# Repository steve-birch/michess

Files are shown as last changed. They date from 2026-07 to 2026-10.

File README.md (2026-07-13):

# michess ♟️

An open-source NFC-based smart chess board powered by a Raspberry Pi. Place any piece on any square and the board knows exactly what it is and where it is - no setup routine, no special starting position required.

The board uses LEDs embedded behind a wood veneer to indicate the chess engine's moves, creating a clean physical interface for playing against a computer opponent.

---

## Features

- **Full piece identification** - NFC tags in each piece base, detected by a matrix of antennas under the board
- **Arbitrary position recognition** - pick up mid-game, set up a puzzle, analyse a position
- **LED move indicators** - subtle lighting behind the veneer shows the engine's chosen move
- **Stockfish integration** - plays via the standard UCI chess engine interface
- **Open design** - all hardware designs and software are freely available

---

## How It Works

64 NFC antennas sit beneath the board, one per square, managed by a hierarchical multiplexer system. A Raspberry Pi 4 scans the full board in under 2 seconds, determines the game state, passes it to Stockfish, and lights up the appropriate squares.

See [`docs/architecture/`](docs/architecture/) for full system diagrams.

---

## Repository Structure

```
michess/
├── hardware/               # Schematics, PCB layouts, BOM, antenna designs
├── firmware/               # Low-level microcontroller code (if applicable)
├── software/
│   ├── board_reader/       # NFC matrix scanning
│   ├── chess_engine/       # Stockfish/UCI integration
│   └── led_controller/     # LED matrix control
├── development/            # Throwaway hardware/learning test harnesses
├── docs/
│   └── architecture/       # System diagrams and design notes
└── tests/
```

---

## Hardware Requirements

| Component | Quantity | Notes |
|---|---|---|
| Raspberry Pi 4 | 1 | Main controller |
| PN532 NFC reader modules | 8 | One per 8-square group |
| CD74HC4067 16-channel multiplexers | 4 | For antenna switching |
| NFC tags (13.56 MHz) | 32 | Embedded in piece bases |
| Custom loop antennas | 64 | One per square, ~1–2 μH |
| WS2812B LEDs | 64+ | For move indication |

See [`hardware/bom/`](hardware/bom/) for a full bill of materials with UK suppliers and current pricing.

---

## Getting Started

### Software Setup

```bash
# Clone the repo
git clone https://github.com/steve-birch/michess.git
cd michess

# Create a Python virtual environment
python3 -m venv venv
source venv/bin/activate

# Install dependencies
pip install -r requirements.txt

# Run
python software/main.py
```

### Hardware Setup

See [`docs/setup.md`](docs/setup.md) for full wiring instructions and assembly guide.

---

## Licences

This project uses different licences for different parts:

| Part | Licence |
|---|---|
| Software | [GPL-3.0](LICENSE) |
| Hardware designs | [CERN-OHL-S v2](hardware/LICENSE) |
| Documentation | [CC BY-SA 4.0](docs/LICENSE) |

In short: you are free to use, modify, and build on michess for any purpose - including building your own board - but you must share any changes under the same terms. Commercial use is permitted, but derived works cannot be closed source.

---

## Contributing

Contributions are very welcome - whether that's hardware improvements, software features, bug fixes, or documentation. Please open an issue first to discuss larger changes.

---

## Project Status

🚧 **Early development** - currently prototyping the NFC matrix on a 2×2 test board.

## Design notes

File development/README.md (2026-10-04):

# development

Throwaway, learning-focused test harnesses used to practice wiring hardware, try out libraries, and de-risk pieces of the design before they get built into the real [`software/`](../software/) stack.

Nothing here is production code. It's not expected to be reused directly: the goal is to fail fast and cheaply while learning the hardware, then carry the *lessons* into `software/`, not necessarily the code itself.

Each subfolder is an independent [uv](https://docs.astral.sh/uv/) project: its own `pyproject.toml`, virtual environment, and lockfile. They don't share code with each other or with `software/`.

## Harnesses

| Folder | Purpose |
|---|---|
| [`nfc-matrix-tester/`](nfc-matrix-tester/) | Wire up a single PN532 reader + tag, then grow into an 8×8 grid visualiser for testing the antenna multiplexer |
| [`st25r-reader-tester/`](st25r-reader-tester/) | Bring up an ST25R3916B MINI over SPI: chip ID check, then tag reads and antenna amplitude/phase (fingerprint) measurements via ST's RFAL driver |

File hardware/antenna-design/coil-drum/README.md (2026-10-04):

# Coil drum

This folder contains a single printed 57 mm chess-square tile for a prototype read coil. The coil sits in a 31.5 mm drum wound between the base plate and a thin top flange that the LED ring passes over. Four locating pegs hold the LED ring in place, with a tail notch for the coil lead and a pocket for the perfboard anchor board.

## Key dimensions

Values are from the draft 2 model (some spreadsheet-driven, some typed in) or from measuring the real parts. The Source column says which.

| Parameter | Value | Source | Notes |
|---|---:|---|---|
| Chess-square tile size | 57 mm | Spreadsheet value `square_size` | Printed square tile size |
| Drum core diameter | 31.5 mm | Spreadsheet value `core_d` | Draft 2 geometry |
| Base plate thickness | 3.6 mm | Typed in | Draft 2 geometry |
| Drum overall height | 6.0 mm | Typed in | Winding gap is 2.4 mm |
| Top flange thickness | 0.6 mm | Typed in | Draft 2 geometry |
| LED ring hole ID | 35 mm | Measured | Measured 2 Oct 2026 |
| LED ring OD | 50 mm | Measured | Measured 2 Oct 2026 |
| LED peg spacing | 32.5 mm | Spreadsheet value `LED_loc_peg_dist` | Locates the LED ring |
| LED hole diameter | 2.2 mm | Spreadsheet value `LED_loc_hole_dia` | Hole size |
| LED peg diameter | 1.2 mm | Spreadsheet value `LED_loc_peg_dia` (= `LED_loc_hole_dia` - `clearance`) | Spreadsheet-driven |
| LED peg height | 5 mm | Typed in | 5 mm from the bottom (1.4 mm above the base plate) |
| Anchor-board pocket height | 1.6 mm | Typed in | Draft 2 geometry |
| Anchor-board pocket floor | 0.6 mm | Typed in | Draft 2 geometry |

## Files

- `coil-drum.FCStd` — FreeCAD 1.1 development build; it may not open in FreeCAD 1.0. The model is driven by a Spreadsheet of named values.
- `coil-drum-Body.stl` — committed STL export for review and reproducibility. If the FCStd changes, re-export the STL in the same commit.

## Printing

- Printer: Bambu Lab A1
- Orientation: flat on its base
- Supports: none
- Layer height / material: TBD

## History

### Draft 1

- Walled winding channel
- Too hard to wind

### Draft 2

- Top flange added
- No wall, flat bottom
- First coil: 3 turns of 30 AWG, wired directly to the ST25R3916B MINI
- Reads an NTAG213 tag
- Rough check only (not measured): read distance looked at least as good as the stock antenna's ~31 mm
- Placing the LED ring (unpowered) over it seemed to reduce the distance
- Known problem: the anchor-board pocket printed mangled, possibly because of the unsupported roof bridge, and the board does not fit; this is to be fixed in draft 3

## Notes

- The design currently mixes spreadsheet-driven values and a few hard-coded values; a tidy-up is still pending.
- The board anchor pocket and the tail notch are in the model.

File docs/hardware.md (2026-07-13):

# Hardware

michess is built around a Raspberry Pi 4 reading a 64-antenna NFC matrix. This page covers the component list, the multiplexer topology, and the LED system.

---

## Bill of Materials

| Component | Quantity | Notes |
|---|---|---|
| Raspberry Pi 4 | 1 | Main controller; 2 GB RAM minimum |
| PN532 NFC reader modules | 8 | One per 8-square group |
| CD74HC4067 16-channel multiplexers | 4 | For antenna switching |
| NFC tags (13.56 MHz, NTAG213) | 32 | Embedded in piece bases |
| Custom loop antennas | 64 | One per square, ~1–2 μH |
| WS2812B LEDs | 64+ | For move indication |

See `hardware/bom/` for a full bill of materials with UK suppliers and current pricing.

---

## NFC Matrix Architecture

### Why a matrix of antennas?

Standard NFC readers have a single antenna with a read range of ~4 cm. To cover all 64 squares without moving parts, michess uses 64 small loop antennas - one per square - switched via multiplexers so that a single PN532 module scans 8 squares in sequence.

### Multiplexer topology

```
Raspberry Pi (I²C / SPI)
    │
    ├─ PN532 #1 ── MUX ── antennas a1–a8
    ├─ PN532 #2 ── MUX ── antennas b1–b8
    ├─ PN532 #3 ── MUX ── antennas c1–c8
    ├─ PN532 #4 ── MUX ── antennas d1–d8
    ├─ PN532 #5 ── MUX ── antennas e1–e8
    ├─ PN532 #6 ── MUX ── antennas f1–f8
    ├─ PN532 #7 ── MUX ── antennas g1–g8
    └─ PN532 #8 ── MUX ── antennas h1–h8
```

Each CD74HC4067 16-channel multiplexer connects one PN532 to 8 antenna coils in sequence (only 8 of the 16 channels are used per MUX). The Pi cycles through all 8 reader modules, reading 8 squares each, giving a full 64-square scan in under 2 seconds.

### Antenna design

The loop antennas are custom-designed PCB coils tuned to 13.56 MHz. Each coil sits directly beneath a board square, routed through the multiplexer to its assigned PN532. See `hardware/antenna-design/` for coil dimensions and tuning notes.

---

## LED System

WS2812B addressable LEDs are placed beneath each square. The Raspberry Pi drives the LED strip directly over a single GPIO pin using the `rpi_ws281x` library. The LEDs indicate:

- **Engine move** - highlight the from-square and to-square
- **Check** - flash the king's square
- **Illegal move** - brief red flash on the lifted piece's origin square

---

## PCB Design

The project uses KiCad for PCB design. Source files are in `hardware/pcb/`. Gerber files are not committed - regenerate them from source when needed.

---

## Enclosure

The enclosure is designed in FreeCAD (source in `hardware/enclosure/`). The top surface is a wood veneer panel with LEDs diffused through it. STL files are not committed - export from the FreeCAD source.

---

## Licences

All hardware designs are released under [CERN-OHL-S v2](https://ohwr.org/cern_ohl_s_v2.txt). You are free to manufacture, modify, and sell boards based on this design, but must share modifications under the same licence.

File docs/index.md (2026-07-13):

# michess

An open-source NFC-based smart chess board powered by a Raspberry Pi. Place any piece on any square and the board knows exactly what it is and where it is - no setup routine, no special starting position required.

The board uses LEDs embedded behind a wood veneer to indicate the chess engine's moves, creating a clean physical interface for playing against a computer opponent.

---

## Features

- **Full piece identification** - NFC tags in each piece base, detected by a matrix of antennas under the board
- **Arbitrary position recognition** - pick up mid-game, set up a puzzle, analyse a position
- **LED move indicators** - subtle lighting behind the veneer shows the engine's chosen move
- **Stockfish integration** - plays via the standard UCI chess engine interface
- **Open design** - all hardware designs and software are freely available

---

## How It Works

64 NFC antennas sit beneath the board, one per square, managed by a hierarchical multiplexer system. A Raspberry Pi 4 scans the full board in under 2 seconds, determines the game state, passes it to Stockfish, and lights up the appropriate squares.

```mermaid
flowchart TB
    NFC["NFC Matrix System\n(64 squares)"] --> Controller
    subgraph Controller["Board Controller (Python)"]
        Reader["Board State Reader"] --> State["Board State Manager"]
        State <--> Engine["Chess Engine Interface (UCI)"]
        State --> Display["LED Display Controller"]
    end
    Controller <--> ChessEngine["Chess Engine\n(Stockfish/GNU Chess)"]
    Controller --> LED["LED Matrix\n(Move Indicators)"]
    User["User Interface\n(Buttons/Display)"] <--> Controller
```

---

## Project Status

> **Early development** - currently prototyping the NFC matrix on a 2×2 test board.

---

## Licences

This project uses different licences for different parts:

| Part | Licence |
|---|---|
| Software | [GPL-3.0](https://www.gnu.org/licenses/gpl-3.0.html) |
| Hardware designs | [CERN-OHL-S v2](https://ohwr.org/cern_ohl_s_v2.txt) |
| Documentation | [CC BY-SA 4.0](https://creativecommons.org/licenses/by-sa/4.0/) |

You are free to use, modify, and build on michess for any purpose - including building your own board - but you must share any changes under the same terms. Commercial use is permitted, but derived works cannot be closed source.

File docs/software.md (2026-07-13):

# Software

The michess software stack is written in Python and runs on the Raspberry Pi. It is split into three modules that communicate through a shared board state.

---

## Architecture

```mermaid
flowchart LR
    board_reader["board_reader\nNFC matrix scanner"] --> state["Board State\n(shared data)"]
    state --> chess_engine["chess_engine\nStockfish / UCI"]
    state --> led_controller["led_controller\nWS2812B strip"]
    chess_engine --> state
```

---

## Modules

### `software/board_reader/`

Scans the 64-square NFC matrix by cycling through the 8 PN532 reader modules and their multiplexed antennas. Returns a snapshot of which NFC tag UIDs are present on which squares.

**Key responsibilities:**

- Drive the CD74HC4067 multiplexers via GPIO
- Poll each PN532 over I²C / SPI
- Map UID → piece identity (from a pre-configured tag registry)
- Emit a `BoardSnapshot` on every scan cycle

### `software/chess_engine/`

Wraps a UCI-compatible chess engine (Stockfish by default, GNU Chess as a fallback). Accepts a board position and returns the engine's chosen move.

**Key responsibilities:**

- Manage the engine subprocess via `python-chess`
- Convert `BoardSnapshot` to a FEN string
- Send position + `go` commands, parse `bestmove` response
- Track game state (whose turn, move history, check/checkmate)

### `software/led_controller/`

Drives the WS2812B LED strip. Listens for display events (move suggestion, check, illegal move) and updates the LEDs accordingly.

**Key responsibilities:**

- Map square coordinates to LED indices
- Animate from-square and to-square highlights
- Flash patterns for check, checkmate, and illegal moves
- Interface with `rpi_ws281x`

---

## Dependencies

| Package | Purpose |
|---|---|
| `python-chess` | Chess logic, FEN, UCI protocol |
| `rpi_ws281x` | WS2812B LED control |
| `adafruit-circuitpython-pn532` | PN532 NFC reader driver |
| `RPi.GPIO` | Multiplexer pin control |

Install all dependencies with:

```bash
pip install -r requirements.txt
```

---

## Running

```bash
# Activate the virtual environment first
source venv/bin/activate

# Run with physical hardware
python software/main.py

# Run in simulated mode (no hardware required)
python software/main.py --simulate
```

---

## Testing

Tests live in `tests/`. Run the full suite with:

```bash
pytest
```

---

## Licences

All software is released under [GPL-3.0](https://www.gnu.org/licenses/gpl-3.0.html). Any modifications or software that incorporates this code must also be released under GPL-3.0.

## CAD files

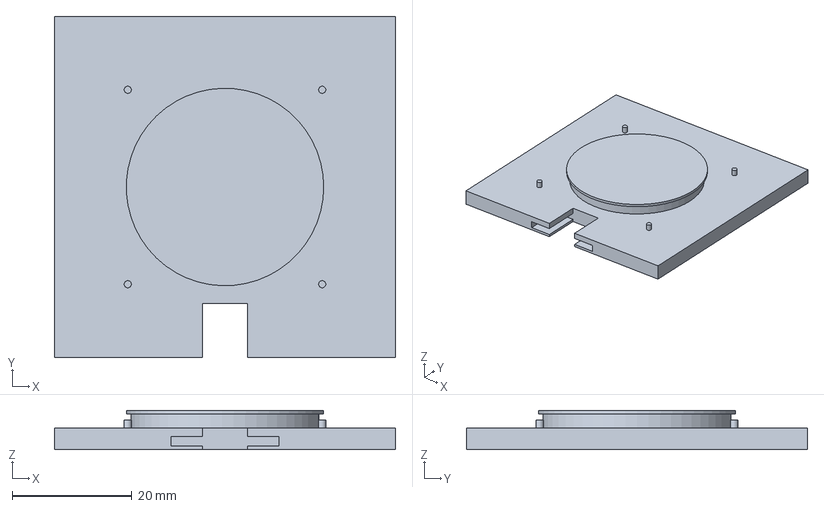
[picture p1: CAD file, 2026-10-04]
hardware/antenna-design/coil-drum/coil-drum.FCStd
57.0 x 57.0 x 6.60 mm

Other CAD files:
hardware/antenna-design/coil-drum/coil-drum-Body.stl

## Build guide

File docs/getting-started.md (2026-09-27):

# Getting Started

This guide covers cloning the repo, setting up the software environment on a Raspberry Pi, and running the board reader for the first time.

---

## Prerequisites

- Raspberry Pi 4 (2 GB RAM or more recommended)
- Raspberry Pi OS (Bookworm or later)
- Python 3.11+
- Git
- [uv](https://docs.astral.sh/uv/) (optional; see Development section)

---

## Software Setup

### 1. Clone the repository

```bash
git clone https://github.com/steve-birch/michess.git
cd michess
```

### 2. Repository-wide or per-harness workflow

The repository contains multiple independent harnesses under `development/`. Each harness is a self-contained Python project with its own `pyproject.toml`, virtual environment, and lockfile. You can either use a single global virtual environment and install needed dependencies, or run each harness in-place using `uv` which will create and manage per-harness virtual environments automatically.

To run the main board reader (if available) via a repo-wide virtual environment:

```bash
python3 -m venv venv
source venv/bin/activate
pip install -r requirements.txt
python software/main.py
```

To run a development harness using `uv` (recommended for prototypes):

```bash
cd development/nfc-matrix-tester
uv run nfc-matrix-tester
```

`uv run` will create the virtual environment and install dependencies automatically on first use.

---

## Hardware Setup

Before running the software you'll need the physical board assembled and wired. See the [Hardware](hardware.md) page for:

- Component list and sourcing
- Wiring diagram / multiplexer topology
- PCB and antenna assembly

---

## Development Setup

If you want to work on the codebase without physical hardware, the board reader supports a simulated mode when running the harness that provides it (see the specific harness README under `development/`). For example, some harnesses accept a `--simulate` flag to emulate hardware.

This lets you develop the chess engine integration and LED controller logic without a connected board.

---

## Repository Layout

```
michess/
├── hardware/               # Schematics, PCB layouts, BOM, antenna designs
├── firmware/               # Low-level microcontroller code (if applicable)
├── software/
│   ├── board_reader/       # NFC matrix scanning
│   ├── chess_engine/       # Stockfish/UCI integration
│   └── led_controller/     # LED matrix control
├── development/            # Throwaway hardware/learning test harnesses (each a self-contained project)
├── docs/
└── tests/
```

---

## Next Steps

- Read the [Hardware](hardware.md) page to understand the physical build
- Read the [Software](software.md) page for architecture details and how to contribute code
- For prototype development, see the README inside each harness under `development/` (for example `development/nfc-matrix-tester/README.md`) for run instructions and available simulate flags

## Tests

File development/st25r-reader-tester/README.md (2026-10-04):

# st25r-reader-tester

Bring-up harness for the Elechouse **ST25R3916B MINI** reader on a Raspberry Pi. This is step 1 of the 4-square prototype plan: prove the reader, SPI link, IRQ line and driver work using only the stock hardware, so any later failure can only be caused by the custom hardware (coils, mux).

## Running it again

- Check you're on the right branch: `git branch --show-current` should print `feature/1-prototype-reading-a-single-nfc-tag`.
- In `development/st25r-reader-tester`, run `uv run id_check.py`. Expect `ID=0x31 type=6`.
- From `vendor/ST25R3916_v2.8.0_Linux_demo_v1.0/linux_demo/build`, run `sudo ./demo/nfc_demo_st25r3916b`; this runs the reader demo, which reads tags with whichever antenna is plugged in. Press `Ctrl+C` to stop it; stop it before swapping antennas.
- `vendor/` is git-ignored, so after a fresh clone you need the unpack, edit and build steps later in this document before the demo will run.

## Status (28 Sep 2026)

| Goal | Result |
|---|---|
| 5V safety check on signal lines | ✅ Pass |
| Chip ID over SPI (Python) | ✅ `type=6` (ST25R3916B) |
| ST RFAL driver builds and runs on Trixie | ✅ |
| Read an NTAG213 tag | ✅ |
| Baseline read distance (stock antenna) | ✅ ~31 mm |
| Does the MINI have AAT varicaps? | ✅ No — fixed matching network, AAT_A/AAT_B unconnected |

## Hardware setup

- Raspberry Pi 4 Model B Rev 1.5, Debian 13 (trixie)
- Connected via a GPIO extension board (T-cobbler) on a breadboard. This is fine for SPI; the breadboard only matters for antenna leads at 13.56 MHz.
- Reader: ST25R3916B MINI with its bundled 52 × 5.5 mm antenna (10 cm cable)

### Wiring

⚠️ The cable colours do **not** follow the usual convention. Red is IRQ, not 5V. Black is CS, not GND. Wire by label, not by colour.

| Wire | Module signal | Pi (cobbler label) | Physical pin |
|---|---|---|---|
| Red | IRQ | GPIO25 | 22 |
| Black | CS | CE0 (GPIO8) | 24 |
| Yellow | SCLK | SCLK (GPIO11) | 23 |
| Green | MOSI | MOSI (GPIO10) | 19 |
| Blue | MISO | MISO (GPIO9) | 21 |
| White | 5V | 5V | 2 |
| Orange | GND | GND | 6 |

IRQ is on **GPIO25**, not GPIO7 as in ST's instructions. GPIO7 is the Pi's second SPI chip-select (CE1), which the SPI driver claims (`/dev/spidev0.1`).

### 5V safety check

The module takes a 5V supply, and the Pi's GPIO pins are not 5V tolerant. So, before connecting any signal wires, the module was powered with only 5V and GND connected, and each signal wire was measured against GND.

| Wire | Reading |
|---|---|
| White (5V) | 5.07 V |
| Red (IRQ) | 0 V |
| Black (CS) | 0.56 V |
| Yellow (SCLK) | 0 V |
| Green (MOSI) | 0.50 V |
| Blue (MISO) | 0 V |

All signal lines were well under 3.3V. Pass.

## Chip ID check (Python)

This is a uv project with `spidev` as its only dependency. SPI must be enabled first (`sudo raspi-config nonint do_spi 0`, then reboot).

```
uv run id_check.py
```

Result: `ID=0x31 type=6 rev=1`. Type 6 means ST25R3916B. `0x00` or `0xFF` would indicate a wiring problem.

## ST RFAL driver (C)

- Source: ST **STSW-ST25R013** from st.com (free account needed), which unpacks to `ST25R3916_v2.8.0_Linux_demo_v1.0`
- It lives in `vendor/`, which is **git-ignored**. ST's licence may not allow redistribution, so re-download it rather than committing it.
- The download file lost its `.tar` extension. To unpack: `unxz STSW-ST25R013.xz`, then `tar -xvf STSW-ST25R013 -C vendor/`

### Local modification (lost on re-extract, so re-apply it)

`linux_demo/platform/st25r3916b/rfal_platform.h`, line 126:

```
#define ST25R_INT_PIN   7   →   25
```

### Build

```
cd vendor/ST25R3916_v2.8.0_Linux_demo_v1.0/linux_demo
mkdir -p build && cd build
cmake -DRFAL_VARIANT=st25r3916b ..
make
```

Gotcha: without the leading `-` on `-D`, CMake silently ignores the setting and builds the **non-B** variant. That build uses the unedited header, so IRQ ends up back on GPIO7. Check that cmake prints `Building st25r3916b Reader/Writer demo`. If you rebuild, delete `build/` first, because CMake caches old settings.

Harmless warnings: the CMake deprecation notice, and a pointer-to-int cast in `rfal_isoDep.c`. The cast is in card-emulation code, which we don't use.

### Run

```
sudo ./demo/nfc_demo_st25r3916b
```

Output with a tag on the antenna:

```
ISO14443A/NFC-A card found. UID: 538D0400A40001
 Read Block: OK Data: 538D045200A40001A5480000E1101200
```

The driver worked on Trixie without changes, apart from the IRQ pin.

## Baseline read distance

| Setup | Result |
|---|---|
| NTAG213 25 mm sticker, flat on the bundled 52 × 5.5 mm antenna, lifted straight up until reads stop | **~31 mm** |

This is the reference for comparing custom coils in bring-up step 4. Elechouse quote ~5 cm with a full-size card, so ~31 mm with a small sticker is in line.

Note: the tag's data block (`E1 10 12 00`) confirms an NDEF-formatted tag with NTAG213 memory size. However, genuine NXP UIDs usually start with `04`, and this one starts with `53`, so it may be a compatible chip from another maker. That's fine for now, but worth remembering if tag performance seems inconsistent.

## AAT status

- **28 Sep 2026:** emailed Elechouse asking whether the MINI has varicaps, for the MINI schematic, and for the antenna inductance the matching network is designed for.
- **Early Oct 2026:** Elechouse confirmed that the MINI has no varicaps, that AAT_A/AAT_B are unconnected, that the matching network is fixed for the bundled ~700 nH antenna, and that no published schematic is available.

With no AAT, each custom coil is wound to behave like the stock antenna, and the chip's amplitude/phase measurement is used as a fingerprint against the stock antenna's reference values. RFAL may provide `rfalChipMeasureAmplitude` / `rfalChipMeasurePhase` (unverified until checked in the vendor headers).

- **Next step (1h):** record the stock antenna's amplitude and phase as the reference.

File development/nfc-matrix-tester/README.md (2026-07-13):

# nfc-matrix-tester

A practice harness for wiring a PN532 NFC reader to a Raspberry Pi and reading tag UIDs: the first step toward the full 64-antenna matrix described in [`docs/hardware.md`](../../docs/hardware.md).

## Current stage

Single PN532, single antenna, single tag. A Tkinter window shows the last UID read.

## Where this is going

Once the CD74HC4067 multiplexers are wired up, this grows into an 8×8 grid: `mux.py` will cycle antenna channels between reads, and `display.py` swaps from a single-label window to a grid of 64 cells that light up as tags are detected. Useful for spotting cross-talk, dead antennas, or bad solder joints during assembly without needing the chess engine/LED stack running.

## Structure

- `reader.py`: talks to the PN532 hardware. The only thing that changes when you move from I²C to SPI, or add the multiplexer.
- `models.py`: `TagRead`, the plain data shape passed from reader to display.
- `display.py`: Tkinter UI. The only thing that changes when this grows from "one label" to "8×8 grid".
- `main.py`: wires reader → display together and runs the poll loop.

## Setup (on the Pi)

```bash
cd development/nfc-matrix-tester
uv sync
```

`uv sync` creates `.venv/` and installs everything pinned in `uv.lock`.

## Run

```bash
uv run nfc-matrix-tester
```

## Checks

```bash
uv run pytest   # tests
uv run mypy     # type checking (strict mode; see [tool.mypy] in pyproject.toml)
```

## Wiring

TODO: fill in once the PN532 is wired up (interface used: I²C/SPI/UART; pins, address).

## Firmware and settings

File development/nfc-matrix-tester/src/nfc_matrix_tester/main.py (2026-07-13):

"""Entry point: poll a single PN532 reader and show results in a Tkinter window."""

from __future__ import annotations

from .display import TkConsole
from .reader import PN532Reader


def main() -> None:
    reader = PN532Reader()
    display = TkConsole()
    display.poll(reader.read_tag)
    display.run()


if __name__ == "__main__":
    main()

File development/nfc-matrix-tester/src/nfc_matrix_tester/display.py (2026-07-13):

"""Tkinter display for tag reads.

Today: a single window showing the last UID seen. Later: swap this
class out for a grid with one cell per square. `main.py`'s call to
`display.update(...)` shouldn't need to change either way.
"""

from __future__ import annotations

import tkinter as tk
from typing import Callable

from .models import TagRead


class TkConsole:
    """Single-label window showing the most recent tag read."""

    WINDOW_TITLE = "NFC Matrix Tester"
    WINDOW_GEOMETRY = "400x150"

    STATUS_FONT = ("monospace", 14)
    UID_FONT = ("monospace", 20, "bold")

    WAITING_TEXT = "Waiting for a tag..."
    NO_UID_TEXT = "--"

    # Default interval (ms) between polls of the reader callback.
    DEFAULT_POLL_INTERVAL_MS = 250

    def __init__(self) -> None:
        self.root = tk.Tk()
        self.root.title(self.WINDOW_TITLE)
        self.root.geometry(self.WINDOW_GEOMETRY)

        self._status = tk.Label(self.root, text=self.WAITING_TEXT, font=self.STATUS_FONT)
        self._status.pack(expand=True)

        self._uid_var = tk.StringVar(value=self.NO_UID_TEXT)
        self._uid_label = tk.Label(
            self.root, textvariable=self._uid_var, font=self.UID_FONT
        )
        self._uid_label.pack(expand=True)

    def update(self, tag_read: TagRead | None) -> None:
        if tag_read is None:
            self._status.config(text=self.WAITING_TEXT)
            return
        self._status.config(text=f"Tag seen at {tag_read.timestamp:%H:%M:%S}")
        self._uid_var.set(tag_read.uid)

    def poll(
        self,
        callback: Callable[[], TagRead | None],
        interval_ms: int = DEFAULT_POLL_INTERVAL_MS,
    ) -> None:
        """Call `callback()` every `interval_ms` and feed the result to `update`."""

        def _tick() -> None:
            self.update(callback())
            self.root.after(interval_ms, _tick)

        self.root.after(interval_ms, _tick)

    def run(self) -> None:
        self.root.mainloop()

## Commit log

2026-05-04 Documentation first cut
2026-09-28 feat(st25r-reader-tester): Add initial ST25R3916B project with chip ID check
    Initializes a new `uv` project for bringing up the ST25R3916B reader via SPI.
    Includes a basic script to verify SPI communication by reading the chip's
    identity register.
2026-09-28 feat(st25r-reader-tester): Document ST25R3916B bring-up and tag reading
    Adds a comprehensive README detailing the hardware setup, SPI verification, ST RFAL
    driver integration, and successful NTAG213 tag reading on a Raspberry Pi.
    This completes the first prototype step of validating the stock reader hardware and driver,
    establishing a baseline for future custom hardware development.
2026-10-04 First draft of the antenna drum with PCB slot
    [coil-drum-Body.stl, coil-drum.FCStd]
2026-10-04 2nd Draft of antenna coil former
    [coil-drum-Body.stl, coil-drum.FCStd]
2026-10-04 docs(coil-drum): restore core diameter and fingerprint plan
2026-10-12 Updated antenna coil drum to have supports for LED ring and to allow perfboard to be screwed in place. Also added guide for wire
2026-10-15 Added fixing holes
2026-10-15 Modified hole locations
